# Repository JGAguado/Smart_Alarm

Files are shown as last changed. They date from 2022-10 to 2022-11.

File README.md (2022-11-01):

[][documentation]
[][releases]
[](LICENSE)

[][maintenance]
[][buymecoffee]

# Smart Alarm
The Smart Alarm is an ESP32-CAM compatible board that integrates a PIR sensor and direct connection with a R503 fingerprint reader device.

<p float="left">
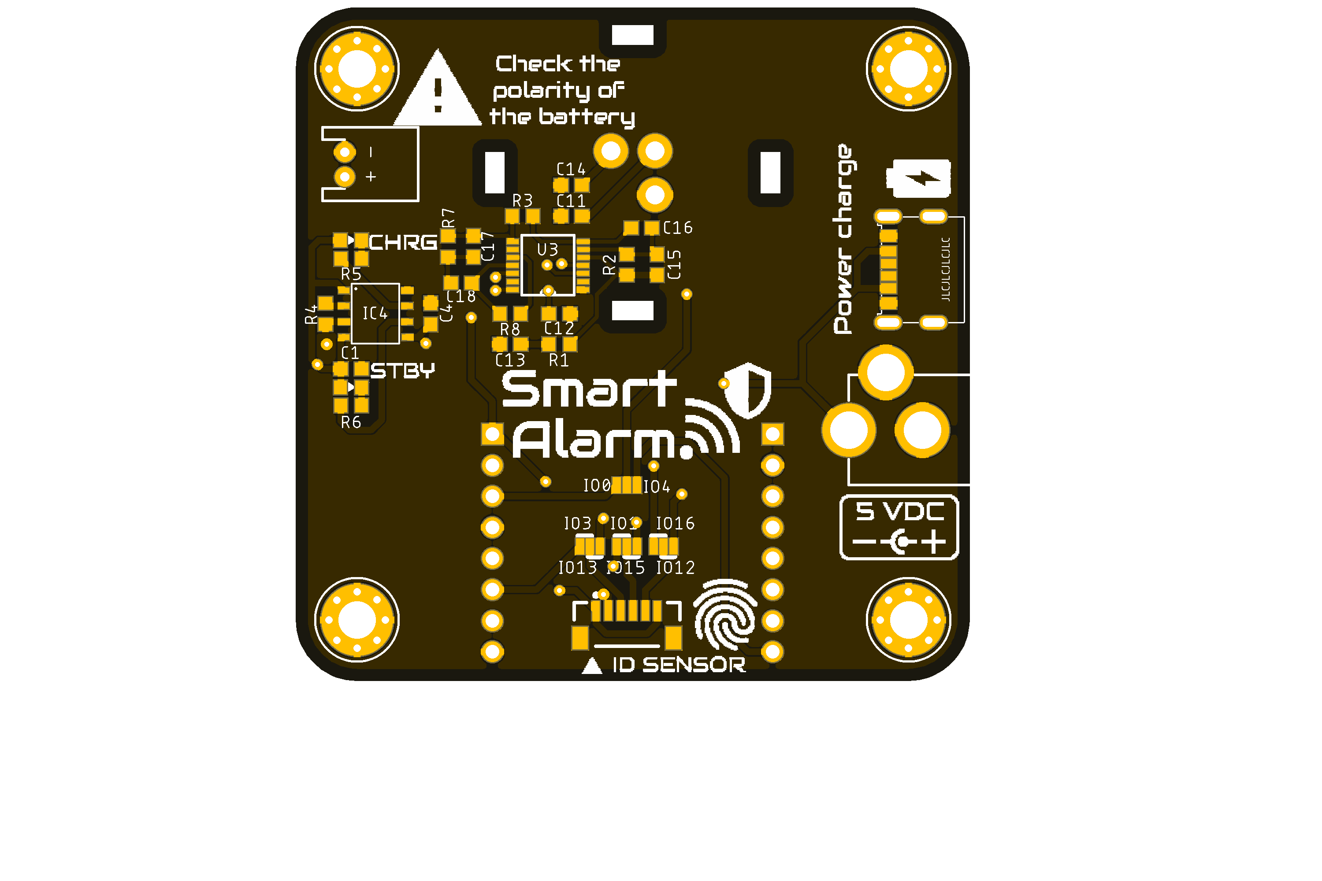
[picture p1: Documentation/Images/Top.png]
   
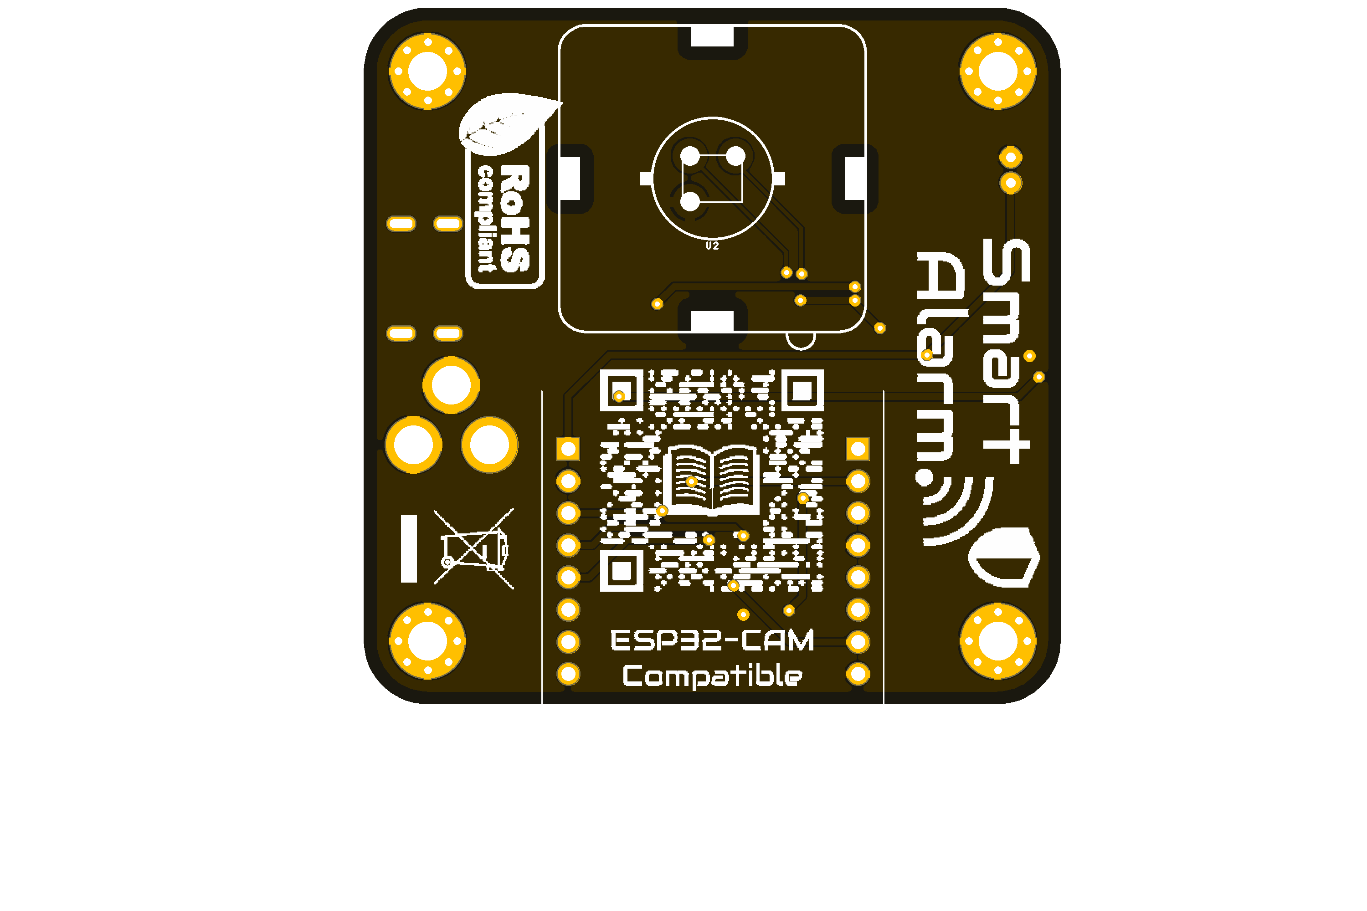
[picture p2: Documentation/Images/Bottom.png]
      
</p>

## Project tree
---
<li><a href="./Design/">Design</a></li>
<li><a href="./Documentation/">Documentation</a></li>

<li><a href="./README.md">README.md</a></li>

[documentation-shield]: https://readthedocs.org/projects/smart-alarm/badge/?version=latest&style=for-the-badge
[documentation]: https://smart-alarm.readthedocs.io/en/latest/

[releases-shield]: https://img.shields.io/github/release/JGAguado/Smart_Alarm.svg?style=for-the-badge
[releases]: https://github.com/JGAguado/Smart_Alarm/releases

[license-shield]: https://img.shields.io/badge/License-CC%20BY--NC--SA%204.0-lightgrey.svg?style=for-the-badge

[maintenance-shield]: https://img.shields.io/badge/maintainer-J.%20G.%20Aguado-blue.svg?style=for-the-badge
[maintenance]: https://github.com/JGAguado

[buymecoffee-shield]: https://img.shields.io/badge/buy%20me%20a%20coffee-support-yellow.svg?style=for-the-badge
[buymecoffee]: https://www.buymeacoffee.com/J.G.Aguado

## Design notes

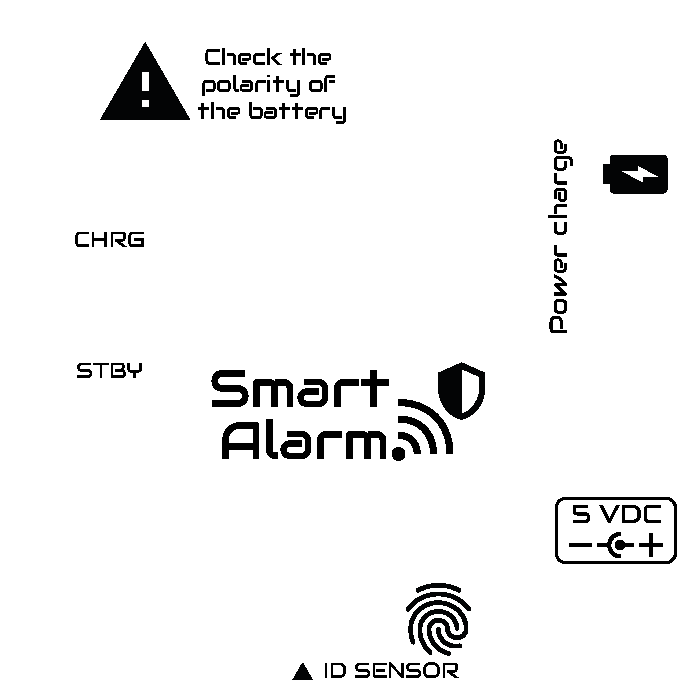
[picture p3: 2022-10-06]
Documentation/Silkscreen/Top.png

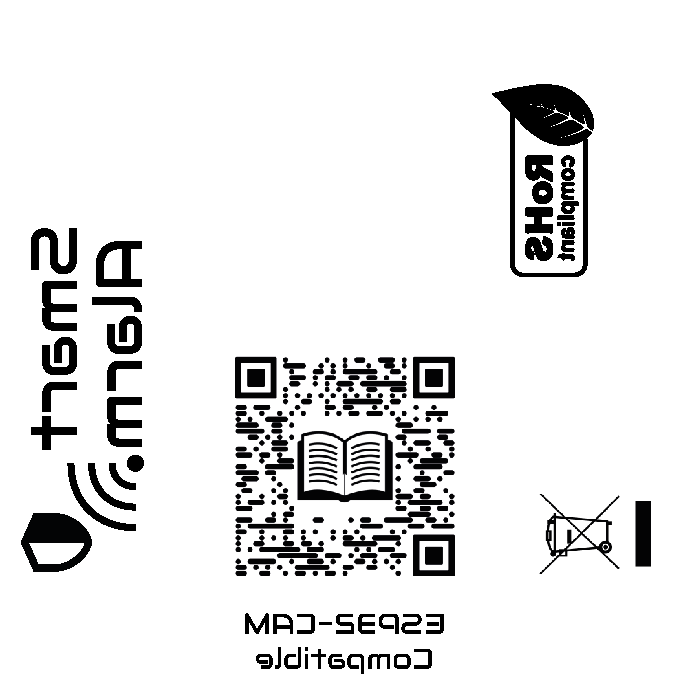
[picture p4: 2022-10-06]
Documentation/Silkscreen/Bottom.png

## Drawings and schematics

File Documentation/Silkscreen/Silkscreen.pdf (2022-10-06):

# Smart Alarm

STBY

ID SENSOR

Power charge

CHRG

### 5 VDC

Check the
polarity of
the battery

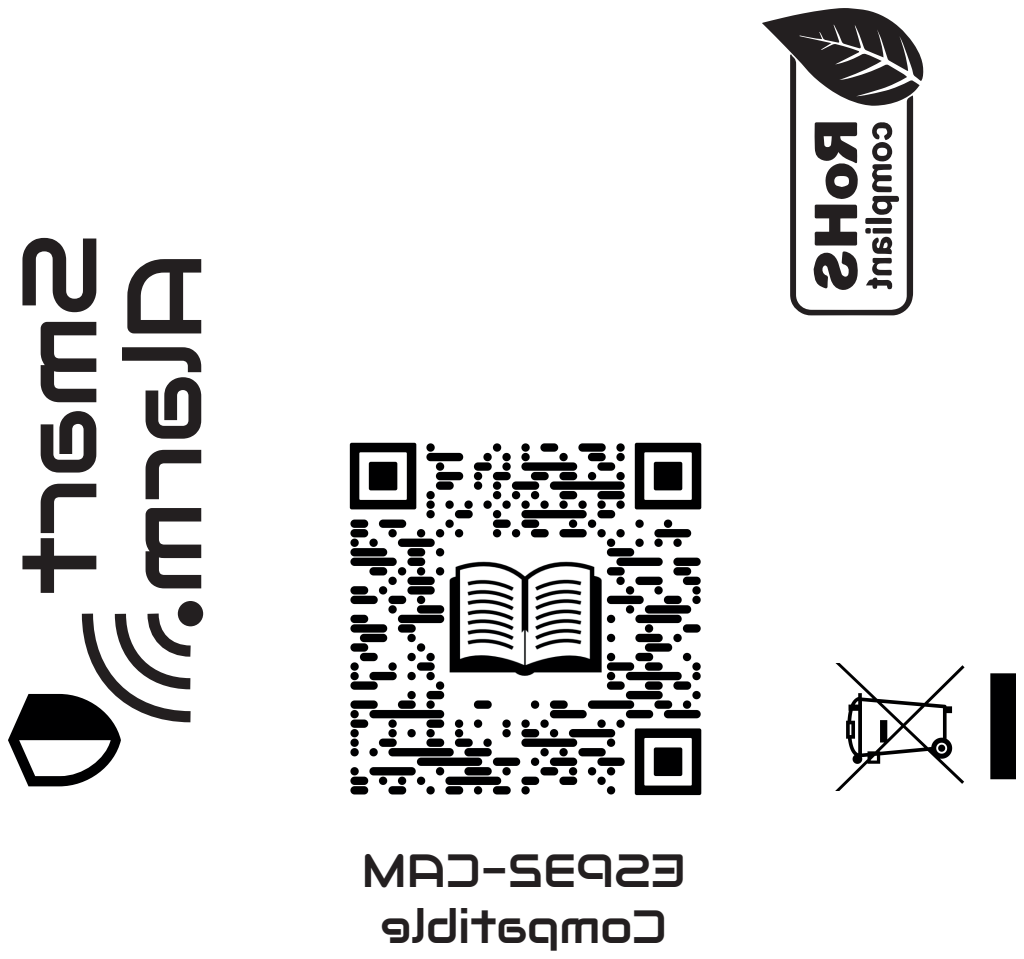
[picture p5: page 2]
Smart Alarm

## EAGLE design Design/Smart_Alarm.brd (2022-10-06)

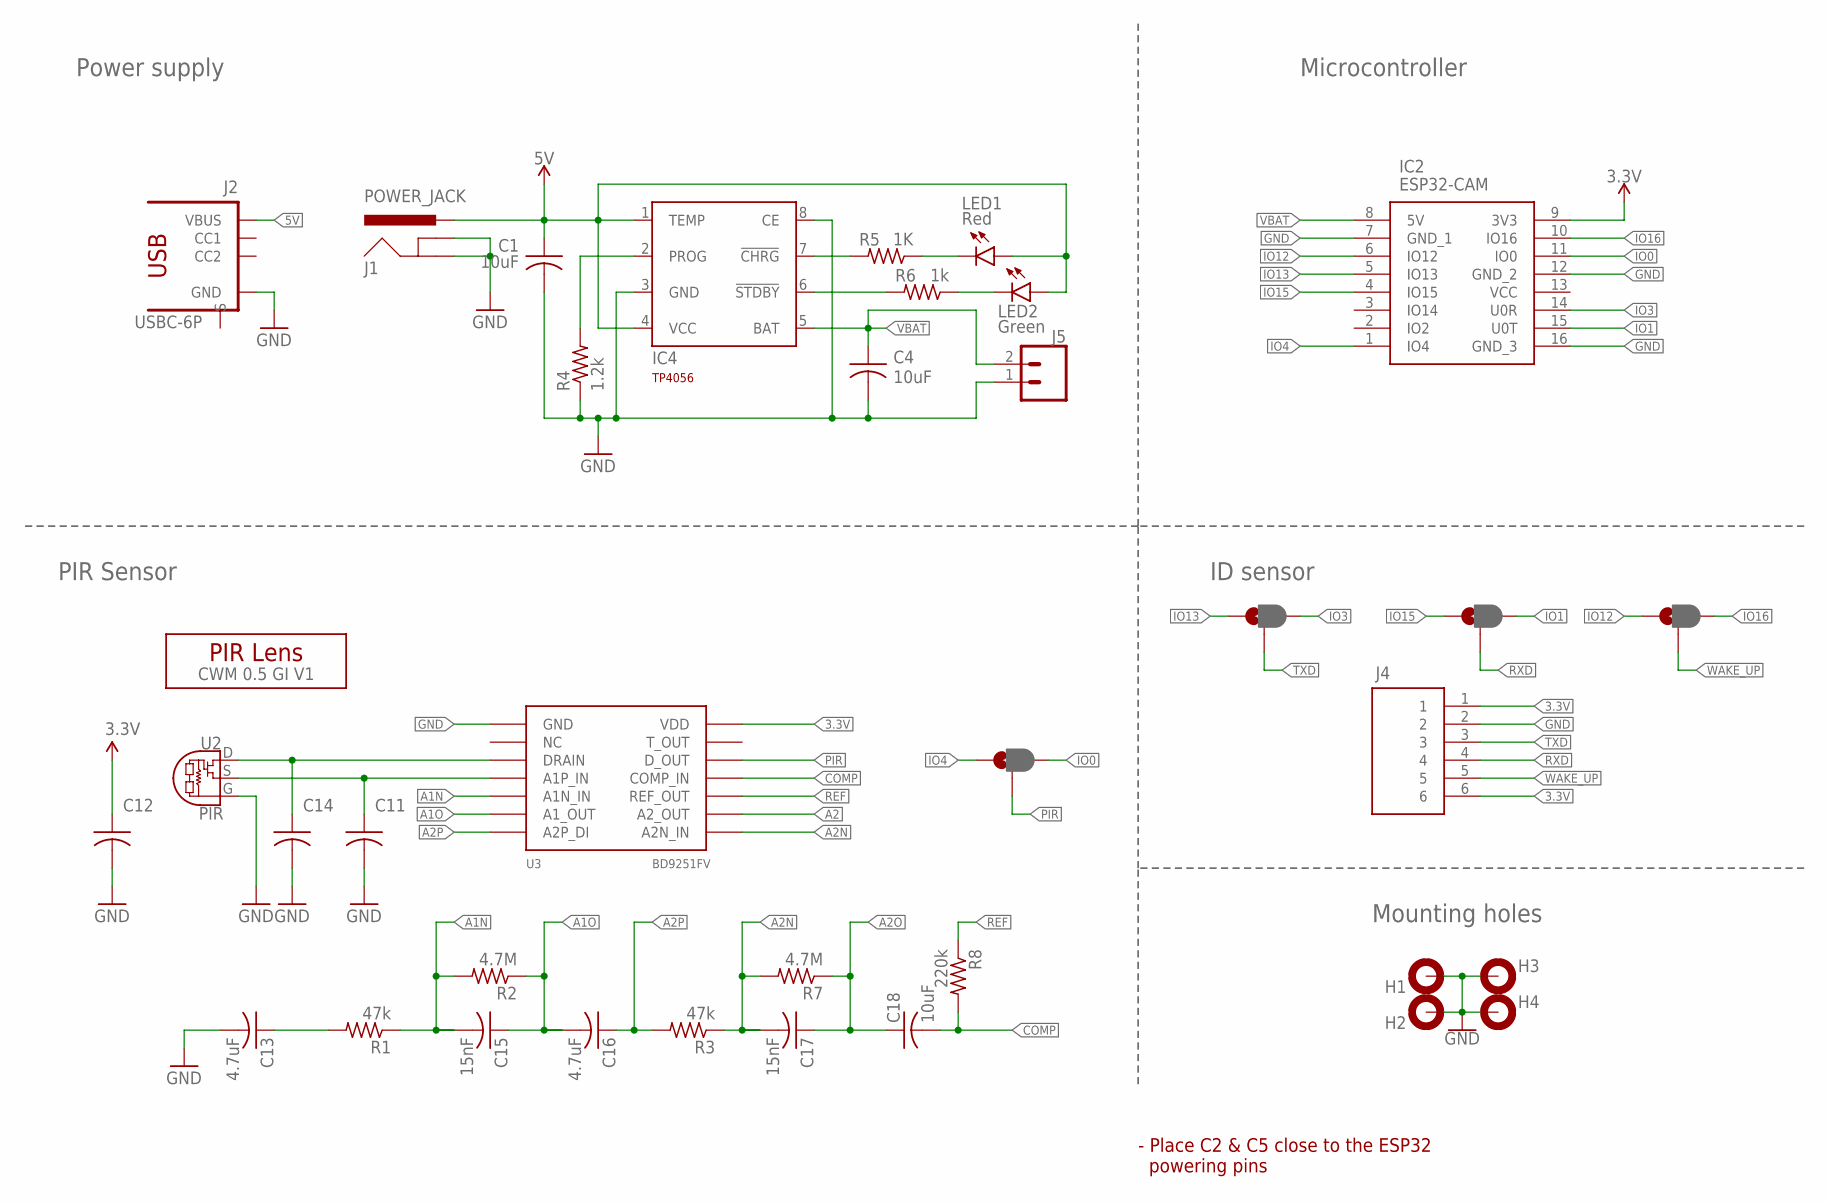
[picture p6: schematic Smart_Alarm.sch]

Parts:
C1, C4, C18: 10uF; C0603
C11, C12, C14: 1.0uF; C0603
C13, C16: 4.7uF; C0603
C15, C17: 15nF; C0603
H1, H2, H3, H4: MOUNT-PAD-ROUND; 3,0-PAD
IC2: ESP32-CAM; ESP32CAM
IC4: TP4056; SOT23-8
J1: POWER_JACK; POWER_JACK_PTH
J2: USBC-6P; USCX-06FX-XXMX-01
J4: JST_6_PIN_VERTICAL; JST-6-SMD-VERT-1.0MM
J5: CONN_02-JST-2-PTH-NO_SILK; JST-2-PTH-NS
JP1, JP2, JP3, JP4: JUMPER-SMT_3_1-NC_PASTE_NO-SILK; SMT-JUMPER_3_1-NC_PASTE_NO-SILK
LED1: Red; LED_0603
LED2: Green; LED_0603
R1, R3: 47k; R0603
R2, R7: 4.7M; R0603
R4: 1.2k; R0603
R5: 1K; R0603
R6: 1k; R0603
R8: 220k; R0603
U2: PIR
U3: BD9251FV; TSSOP-14
U$2: CWM 0.5 GI V1; LENS-CWM-0.5-GI-V1

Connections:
3.3V: C12.1, IC2.9 (3V3), J4.1, J4.6, U3.14 (VDD)
5V: C1.1, IC4.1 (TEMP), IC4.4 (VCC), J1.PWR, J2.VBUS1 (VBUS), J2.VBUS2 (VBUS), LED1.A, LED2.A
A1N: C15.2, R1.1, R2.2, U3.5 (A1N_IN)
A1O: C15.1, C16.2, R2.1, U3.6 (A1_OUT)
A2: U3.9 (A2_OUT)
A2N: C17.2, R3.1, R7.2, U3.8 (A2N_IN)
A2O: C17.1, C18.1, R7.1
A2P: C16.1, R3.2, U3.7 (A2P_DI)
COMP: C18.2, R8.2, U3.11 (COMP_IN)
GND: C1.2, C4.2, C11.2, C12.2, C13.2, C14.2, H1.B3,0, H1.P$2, H1.P$3, H1.P$4, H1.P$5, H1.P$6, H1.P$7, H1.P$8, H1.P$9, H2.B3,0, H2.P$2, H2.P$3, H2.P$4, H2.P$5, H2.P$6, H2.P$7, H2.P$8, H2.P$9, H3.B3,0, H3.P$2, H3.P$3, H3.P$4, H3.P$5, H3.P$6, H3.P$7, H3.P$8, H3.P$9, H4.B3,0, H4.P$2, H4.P$3, H4.P$4, H4.P$5, H4.P$6, H4.P$7, H4.P$8, H4.P$9, IC2.7 (GND_1), IC2.12 (GND_2), IC2.16 (GND_3), IC4.3 (GND), IC4.8 (CE), J1.GND, J1.GNDBREAK, J2.GND1 (GND), J2.GND2 (GND), J4.2, J5.1, R4.1, U2.G, U3.1 (GND)
IO0: IC2.11 (IO0), JP4.3
IO1: IC2.15 (U0T), JP2.3
IO3: IC2.14 (U0R), JP1.3
IO4: IC2.1 (IO4), JP4.1
IO12: IC2.6 (IO12), JP3.1
IO13: IC2.5 (IO13), JP1.1
IO15: IC2.4 (IO15), JP2.1
IO16: IC2.10 (IO16), JP3.3
unnamed: LED1.C, R5.1
unnamed: IC4.6 (!STDBY), R6.2
unnamed: LED2.C, R6.1
unnamed: IC4.2 (PROG), R4.2
unnamed: IC4.7 (!CHRG), R5.2
unnamed: C11.1, U2.S, U3.4 (A1P_IN)
unnamed: C14.1, U2.D, U3.3 (DRAIN)
unnamed: C13.1, R1.2
PIR: JP4.2, U3.12 (D_OUT)
REF: R8.1, U3.10 (REF_OUT)
RXD: J4.4, JP2.2
TXD: J4.3, JP1.2
VBAT: C4.1, IC2.8 (5V), IC4.5 (BAT), J5.2
WAKE_UP: J4.5, JP3.2

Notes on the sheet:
- Place C2 & C5 close to the ESP32 powering pins
PIR Sensor
Mounting holes
Microcontroller
Power supply
ID sensor

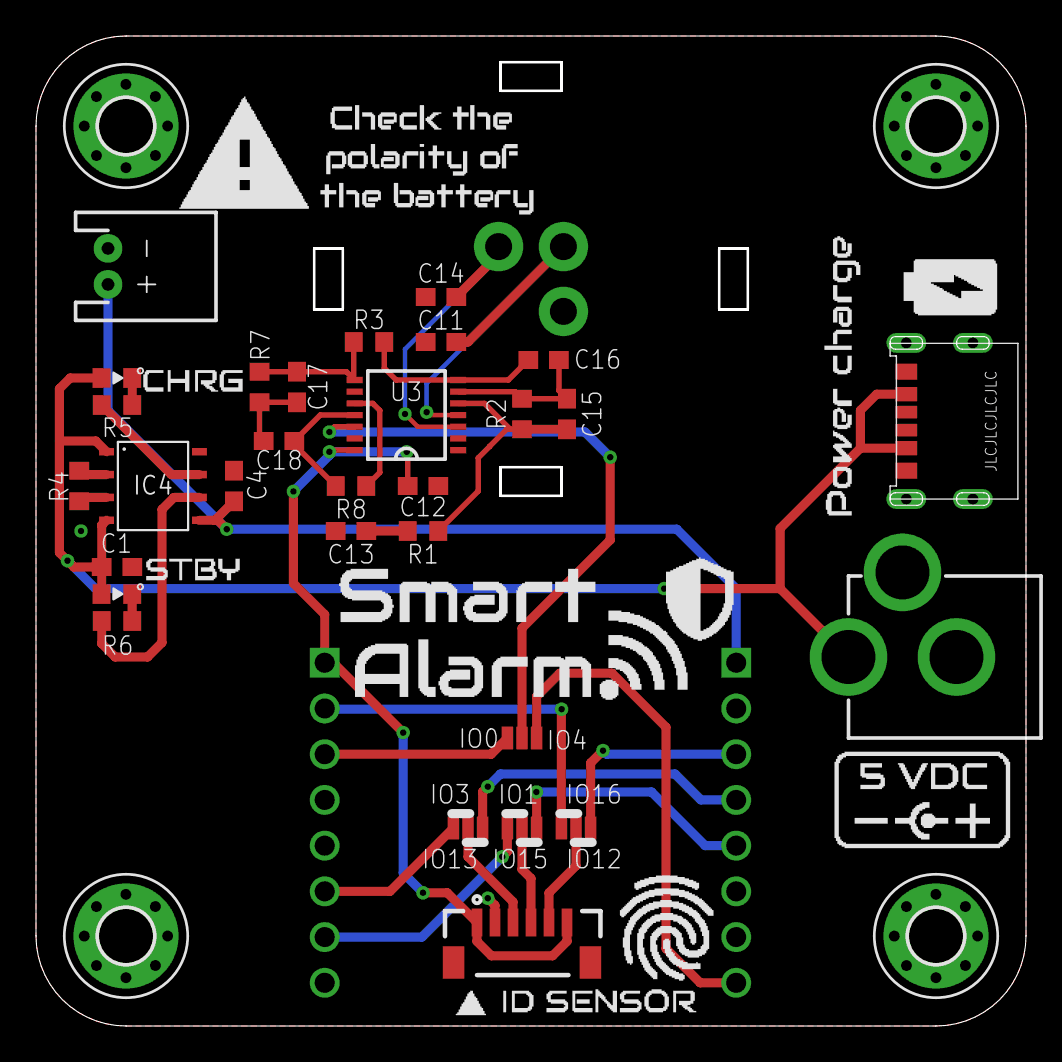
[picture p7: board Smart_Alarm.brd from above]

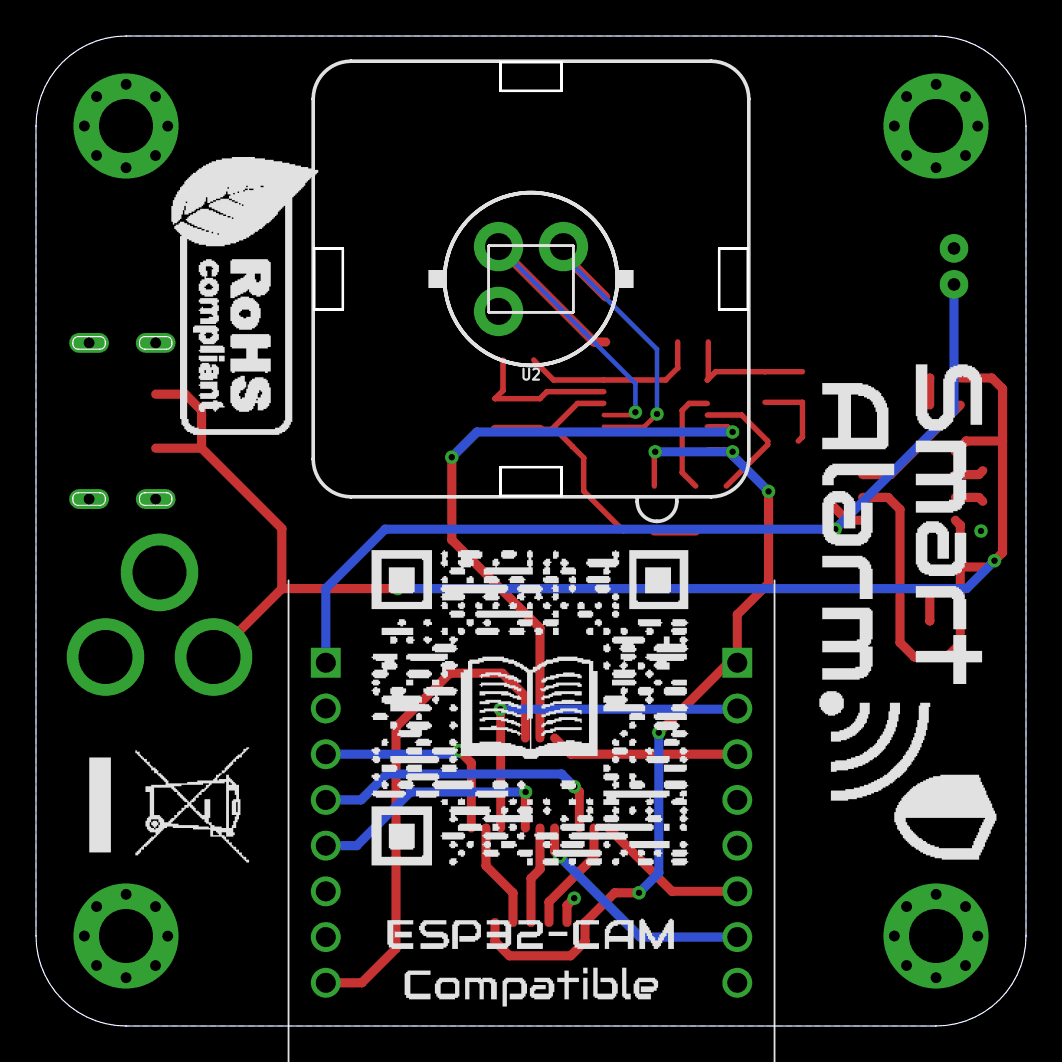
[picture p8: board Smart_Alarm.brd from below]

Board: 2 copper layers, 55.0 x 55.0 mm, 37 parts (3 on the bottom side), 31 nets.

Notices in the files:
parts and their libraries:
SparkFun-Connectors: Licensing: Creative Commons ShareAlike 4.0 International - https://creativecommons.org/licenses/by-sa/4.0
